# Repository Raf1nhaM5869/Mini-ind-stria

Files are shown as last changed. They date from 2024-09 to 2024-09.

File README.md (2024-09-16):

# Mini Indústria - Robótica
<div align="center">
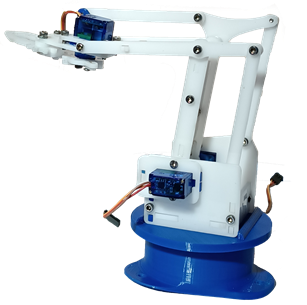
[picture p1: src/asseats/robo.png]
  
</div>

## Realizador
- Rafael Melo (up202405969@fe.up.pt)

## Introdução ao projeto

No ano letivo 2023/2024, no seguimento da apresentação de atividades de Física no Dia da Ciência (24 de novembro), decidi continuar a divulgação de novos trabalhos. Assim, resolvi fazer um projeto que unia diversas áreas científicas, desde a mecânica, eletrónica e informática.
O projeto consiste na simulação do funcionamento de uma secção da indústria, utilizando um braço mecânico e uma passadeira rolante, com os respetivos motores e circuitos, tendo também em conta a sustentabilidade do projeto, que reutilizou materiais, dando-lhes novo uso.
O principal objetivo foi simular uma linha de montagem, que através da união das áreas anteriormente referias, foi possível criar uma passadeira rolante e um pequeno robô, capazes de transportar objetos, através de um comando de PlayStation 3.

## Objetivo do projeto
Na elaboração do projeto, tive como objetivo criar um braço robótico capaz de movimentar um objeto através de motores servos e uma passadeira que transporta um objeto de uma forma estável e rápida.  
Sendo assim, com a criação da passadeira rolante e do braço robótico o funcionamento deveria ser o seguinte: o produto fabricado chegava ao início da passadeira rolante, e este ia percorrer até alcançar o final da mesma. Logo a seguir, o produto para e o robô está pronto a pegá-lo e deslocá-lo para o local desejado. 
Quando o robô pega no produto, este é controlado através de um comando de PlayStation 3, em que os analógicos são usados para obter maior precisão, no decorrer da tarefa. 

## Materiais utilizados
### Braço Robótico 
- `4 motores servo`
  - Os motores servos foram utilizados para articular o braço robótico.  
- `Estrutura do braço em acrílico`

- `Comando de PlayStation 3` 
   - Através do comando de PlayStation , o utilizador consegue controlar o robô, movendo os analógicos, enviando os dados através de Bluetooth para o ESP32.

- `ESP32`
   - O ESP32 permite a comunicação entre o comando PlayStation 3 e os motores servos, permitindo a coordenação entre ambos. 
- `Fio de ligação`

### Passadeira Rolante
- `Borracha`
- `Dois Cilindros de Plástico` 
- `2 Motores de Passo` 
  - Os motores de passos permitem movimentação da passadeira rolante. 
- `Arduíno Uno`
  - O Arduíno Uno permite controlar a velocidade dos motores de passo enviado dados para o módulo L298N e obtém informação através do sonar.
- `Fios de Ligação` 
- `Sonar`

### Equipamento extra
- `Impressora 3D`
  - A impressora 3D permitiu imprimir todas as peças. Assim, obtendo um melhor desempenho no projeto. A marca da impressora é TWO TREES
- `Equipamento de Solda`
- `Multímetro`
- `Transformadores` 
- `Paquímetro`
- `Topia`
### Software 
- `Arduíno IDE`
  - O Arduíno IDE foi o utilizado para programar todos os componentes, como por exemplo, o ESP32, Arduíno Uno, sonar, motores, etc. A linguagem utilizada foi o C++.

- `Fusion 360` 
  - O fusion 360 é um programa de design 3D capaz de satisfazer as necessidades do projeto, uma vez que é possível fazer peças em 3D de uma forma rápida e precisa. Para além disso, no final do projeto, obtenho o ficheiro em STL, possibilitando a sua impressão. 
- `Ultimaker Cura`
  - O Ultimaker Cura é um programa que ajuda a conectar a impressora 3D e definir as características de impressão de cada peça. Através deste software, consegue-se mudar a temperatura de bico de impressão, percentagem de preenchimento, altura do bico ao prato de impressão, velocidade, etc.
- `Fritzing`
  - O Fritzing foi usado para fazer o rascunho dos circuitos elétricos.

<div style="white-space: nowrap;">
  <a href="https://www.arduino.cc/en/software">
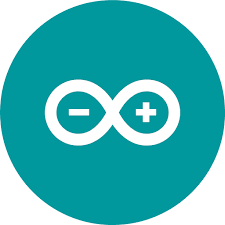
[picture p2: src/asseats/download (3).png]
    
  </a>

  <a href="https://www.autodesk.com/">
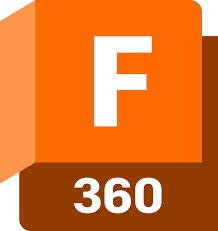
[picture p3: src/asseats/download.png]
    
  </a>

  <a href="https://ultimaker.com/">
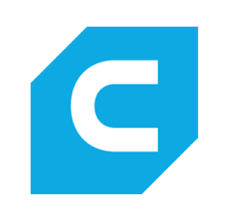
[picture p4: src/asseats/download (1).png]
    
  </a>

  <a href="https://fritzing.org/">
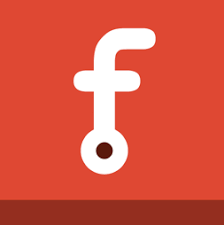
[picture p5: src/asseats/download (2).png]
    
  </a>
</div>

## Implementação
No início do projeto, houve a compra de um kit de um braço robótico em acrílico. Contudo, através da montagem do mesmo, foi detetado diversas anomalias que iam afetar diretamente o devido funcionamento. Sendo assim, efetuei uma análise pormenorizada para solucionar os problemas apresentados no decorrer da montagem. Estes problemas incidiam na parte estrutural, uma vez que toda a estrutura do robô estava afixada no eixo de um motor servo e apresentava algumas peças partidas.
Sendo assim, para criar as estruturas necessárias, utilizou-se a impressora 3D, capaz de fabricar peças personalizadas (tridimensionais e feitas de plástico bastante resistente). 
Assim, para melhorar o desempenho do robô, tive de recorrer à ferramenta anteriormente referia, sendo capaz de resolvê-los. Assim projetaram-se peças com recurso ao FUSION 360.

Nota: Para obter as medidas das peças desejadas necessitei de um paquímetro.
## Peças fabricadas para o braço robótico
### Esta peça é um suporte do braço robótico
Cada imagem está associada a um ficheiro stl da peça.
<p align="center">
  <a href="https://github.com/Raf1nhaM5869/Mini-industria/blob/main/src/objetos%203d/suporte_base.stl">
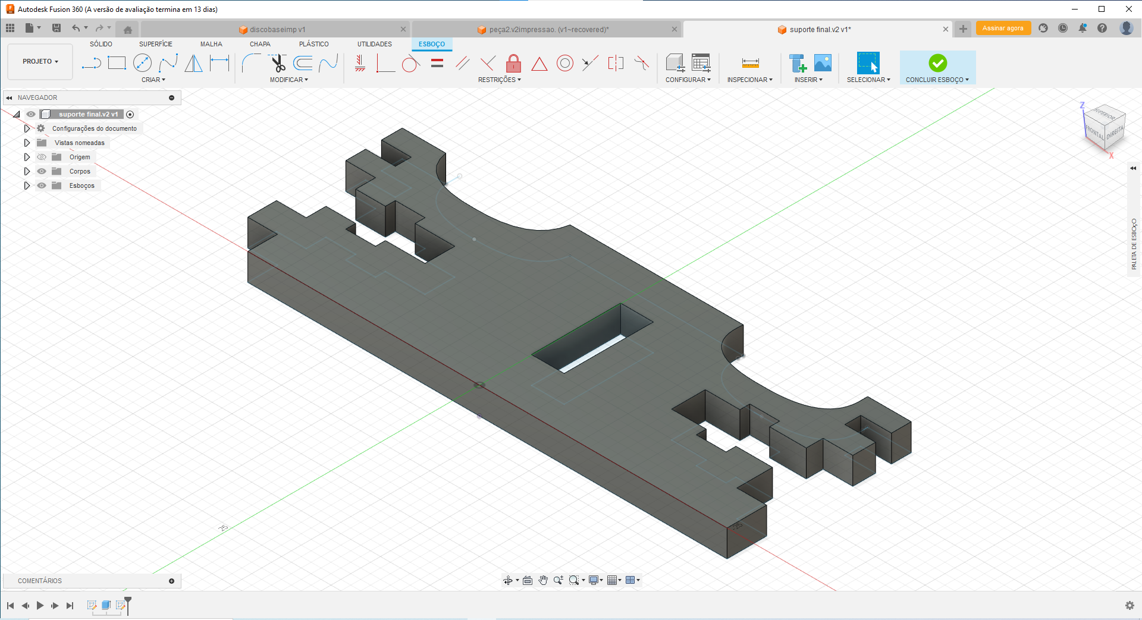
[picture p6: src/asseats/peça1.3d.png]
    
  </a>
  <a href="https://github.com/Raf1nhaM5869/Mini-industria/blob/main/src/asseats/IMG_20231211_163835.jpg">
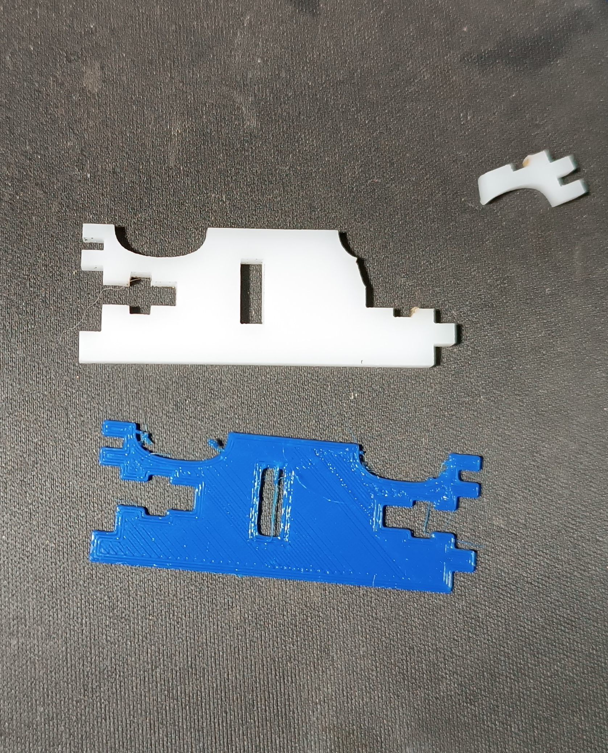
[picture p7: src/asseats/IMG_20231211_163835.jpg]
    
  </a>
</p>

### Suporte da garra à restante estrutura
<p align="center">
  <a href="https://github.com/Raf1nhaM5869/Mini-industria/blob/main/src/objetos%203d/suport_cabe%C3%A7a2.stl">
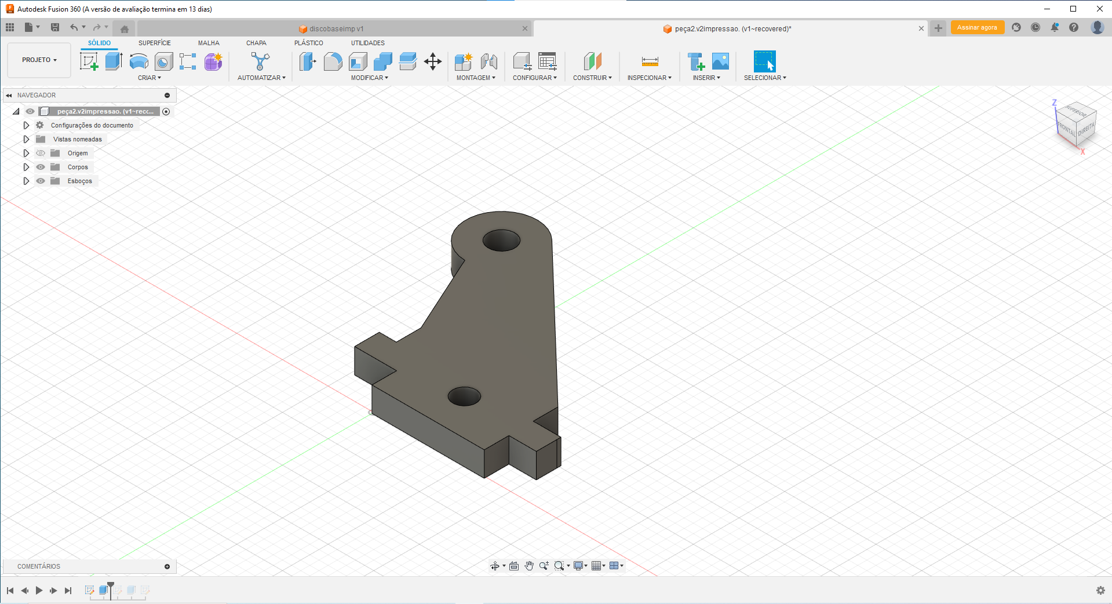
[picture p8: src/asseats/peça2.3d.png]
    
  </a>
  <a href="https://github.com/Raf1nhaM5869/Mini-industria/blob/main/src/objetos%203d/suport_cabe%C3%A7a.stl">
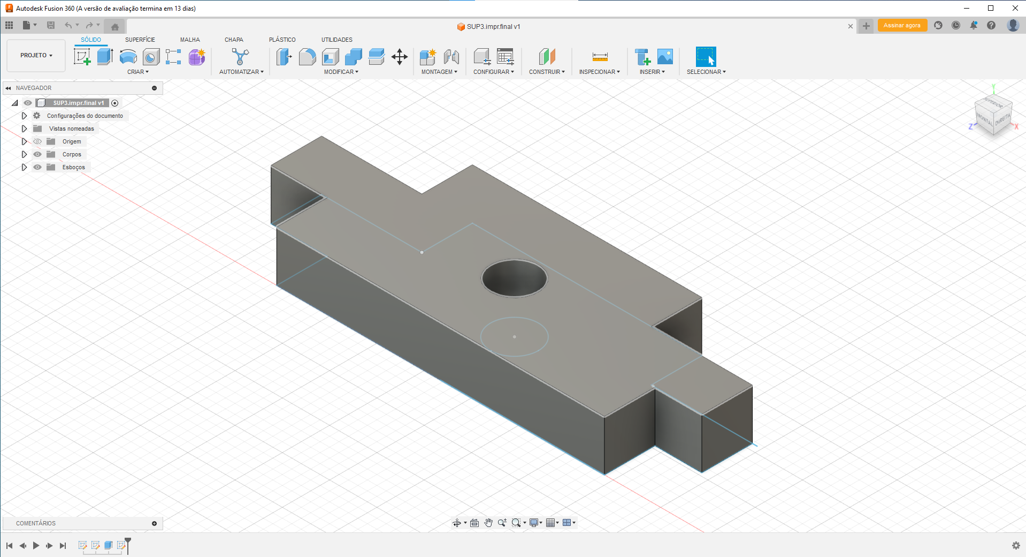
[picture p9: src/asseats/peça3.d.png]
    
  </a>
</p>

<p align="center">
  <a href="https://github.com/Raf1nhaM5869/Mini-industria/blob/main/src/asseats/IMG_20240914_143653.jpg">
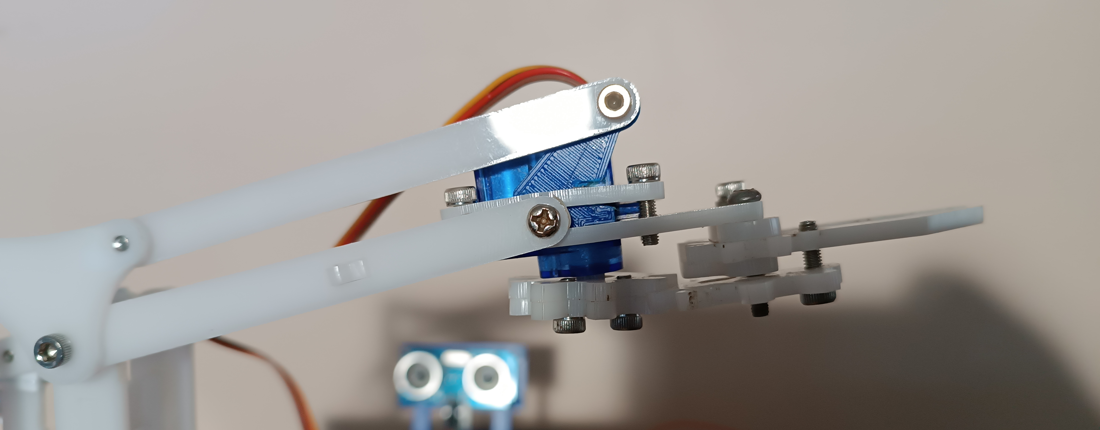
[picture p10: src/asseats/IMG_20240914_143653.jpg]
    
  </a>
  <a href="https://github.com/Raf1nhaM5869/Mini-industria/blob/main/src/asseats/IMG_20240914_143512.jpg">
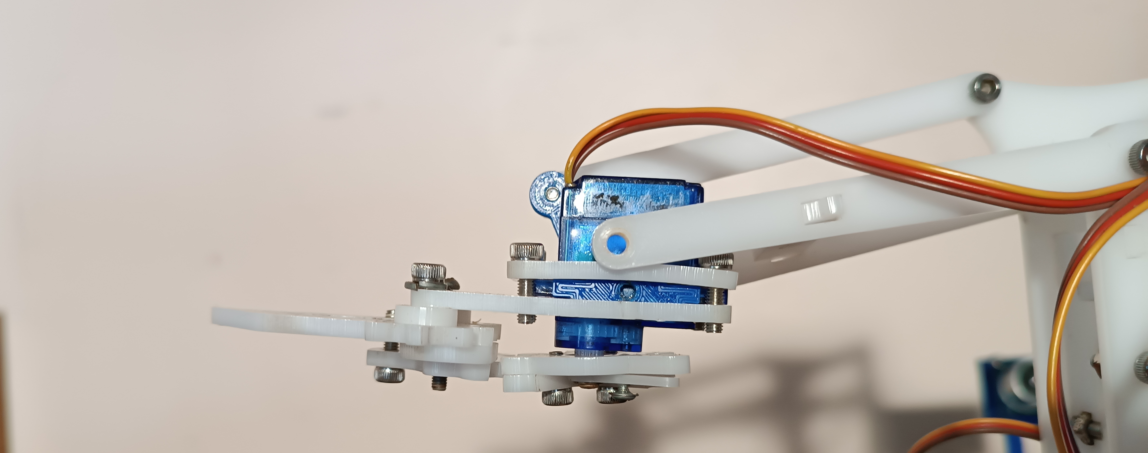
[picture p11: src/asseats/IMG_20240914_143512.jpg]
    
  </a>
</p>

### Disco da Base
<p align="center">
  <a href="https://github.com/Raf1nhaM5869/Mini-industria/blob/main/src/objetos%203d/suport_disco_robo.stl">
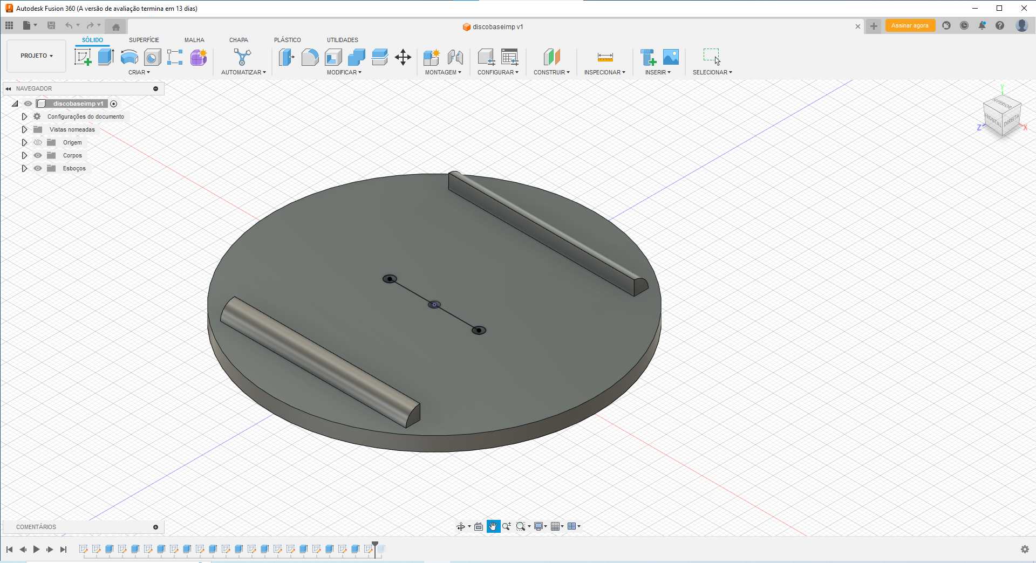
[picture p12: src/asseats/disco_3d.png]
    
  </a>
  <a href="https://github.com/Raf1nhaM5869/Mini-industria/blob/main/src/asseats/IMG_20231218_215923.jpg">
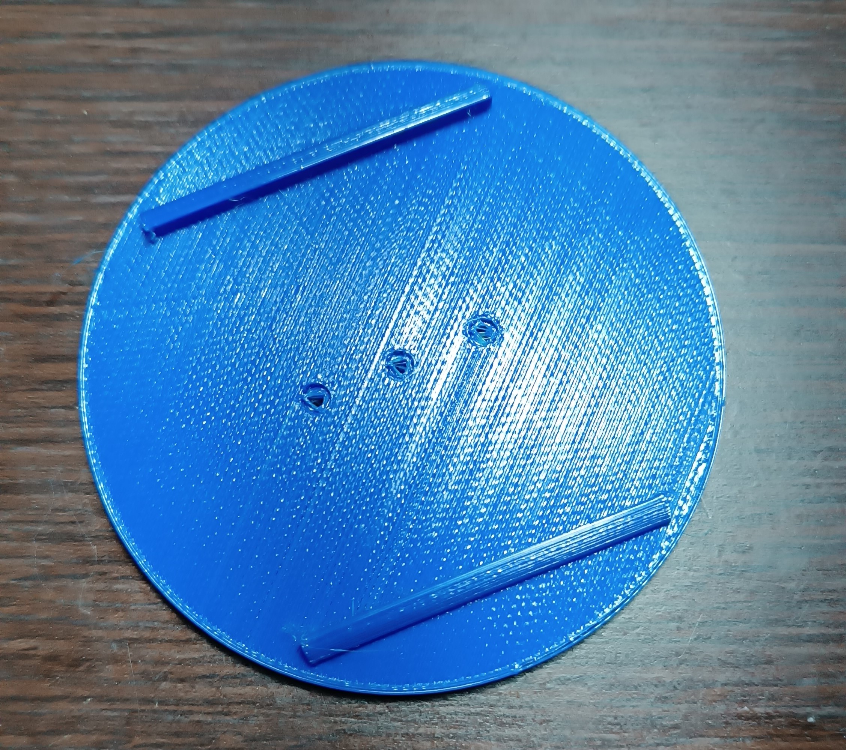
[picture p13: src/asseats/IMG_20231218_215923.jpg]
    
  </a>
</p>

### Base do robô

<p align="center">
  <a href="https://github.com/Raf1nhaM5869/Mini-industria/blob/main/src/objetos%203d/base.stl">
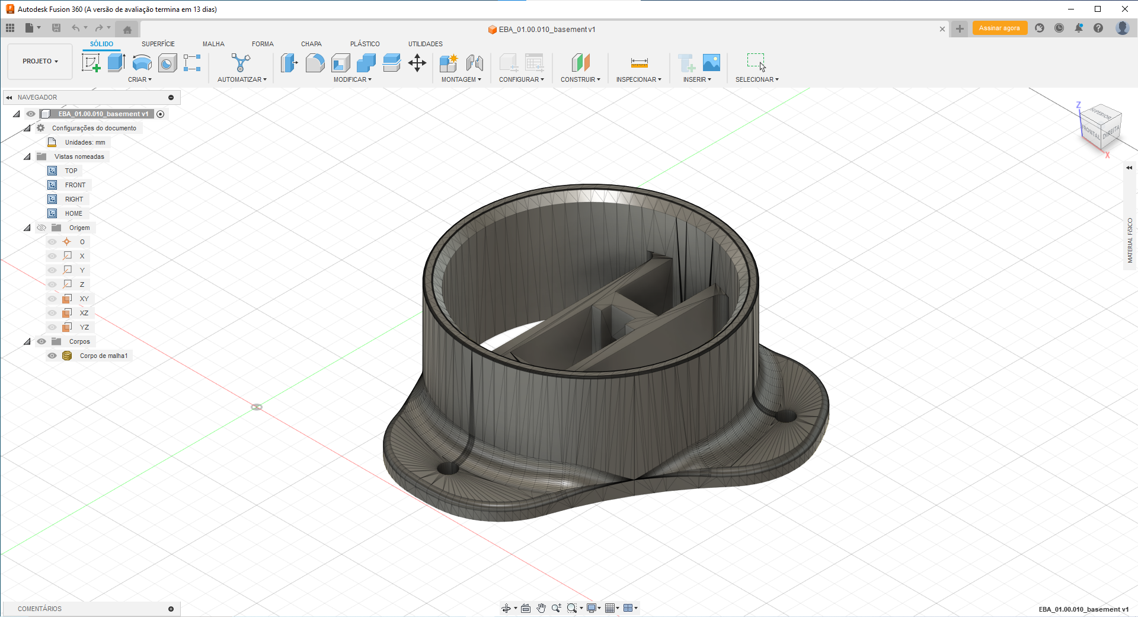
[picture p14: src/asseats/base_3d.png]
Base 3D
    
  </a>
  <a href="https://github.com/Raf1nhaM5869/Mini-industria/blob/main/src/asseats/IMG_20231217_211504.jpg">
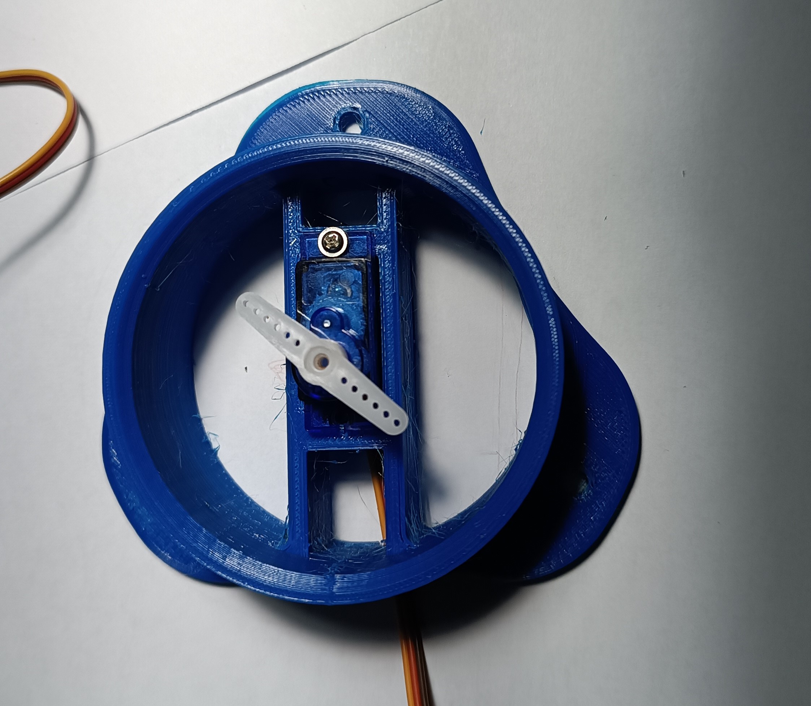
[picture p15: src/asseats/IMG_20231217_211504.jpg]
    
  </a>
</p>

Logo após a criação das peças no fusion 360, estas foram impressas na impressora 3D. Depois de finalizar a impressão 3D, houve a montagem de todas as peças. Antes / depois, respetivamente.

<p align="center">
  <a href="https://github.com/Raf1nhaM5869/Mini-industria/blob/main/src/asseats/IMG_20231128_140823.jpg">
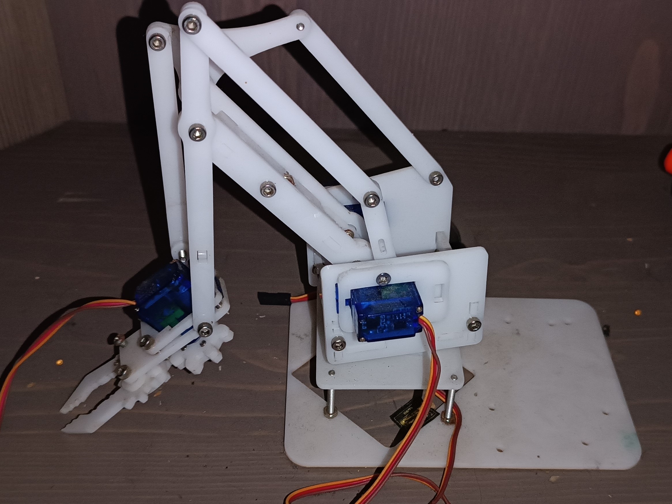
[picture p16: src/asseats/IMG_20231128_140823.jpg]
    
  </a>
  <a href="https://github.com/Raf1nhaM5869/Mini-industria/blob/main/src/asseats/IMG_20240115_205545.jpg">
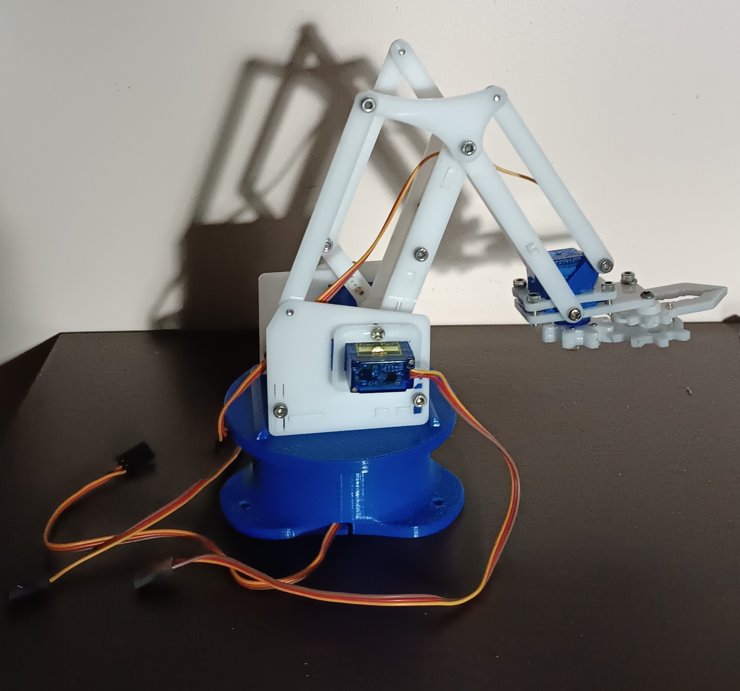
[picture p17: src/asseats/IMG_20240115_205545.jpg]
    
  </a>
</p>

### Instalação do circuito elétrico do robô
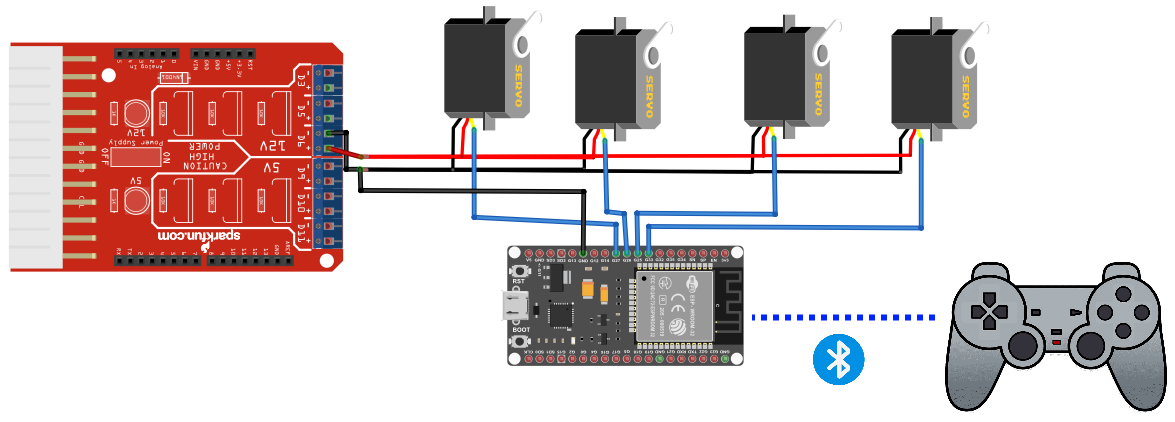
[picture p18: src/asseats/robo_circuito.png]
 

## Peças fabricadas para a passadeira rolante
Na passadeira rolante houve também a necessidade de recorrer ao uso da impressão 3D, para obter estabilidade e mobilidade do tapete. Sendo assim, fiz quatro peças que são as seguintes:

### Espaçador
<p align="center">
  <a href="https://github.com/Raf1nhaM5869/Mini-industria/blob/main/src/objetos%203d/roda.stl">
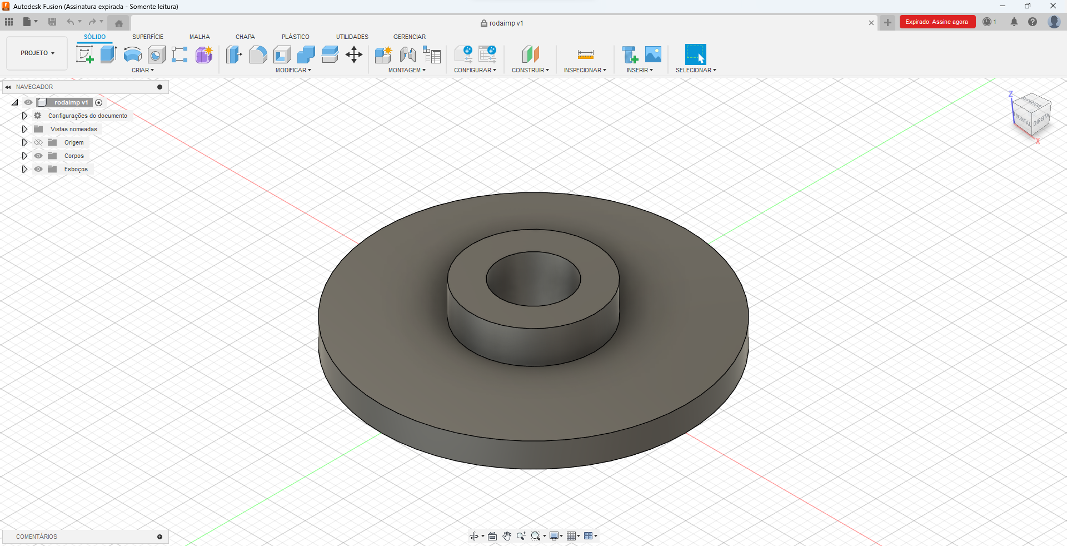
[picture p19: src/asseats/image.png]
    
  </a>
  <a href="https://github.com/Raf1nhaM5869/Mini-industria/blob/main/src/asseats/IMG_20240428_230101.jpg">
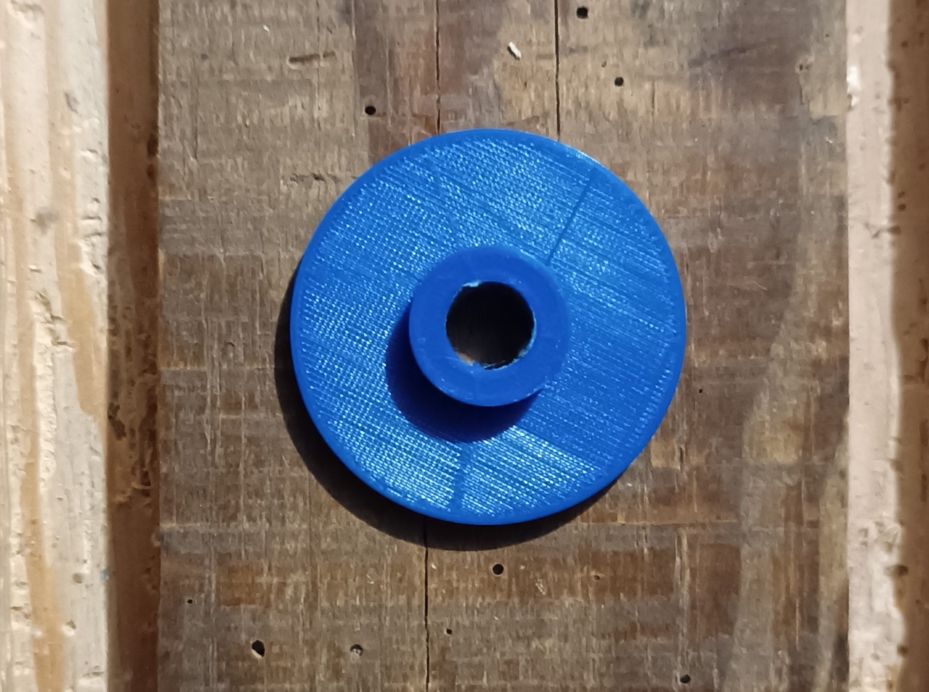
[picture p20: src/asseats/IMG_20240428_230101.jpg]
    
  </a>
</p>

Esta peça foi impressa duas vezes para bloquear a movimentação do rolo de plástico (na horizontal) para não alterar a trajetória.
### Disco Protetor
<p align="center">
  <a href="https://github.com/Raf1nhaM5869/Mini-industria/blob/main/src/objetos%203d/disco_protect.stl">
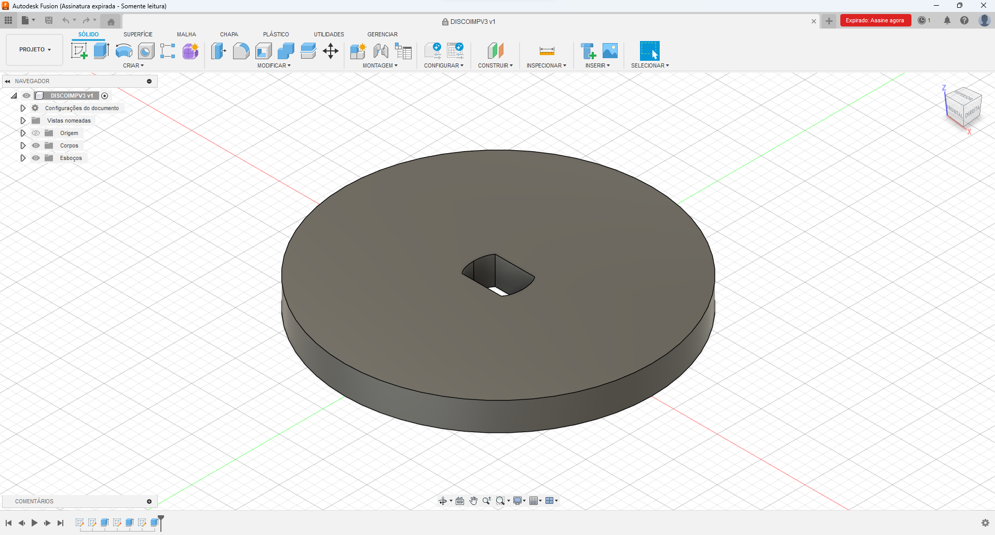
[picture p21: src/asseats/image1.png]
    
  </a>
  <a href="https://github.com/Raf1nhaM5869/Mini-industria/blob/main/src/asseats/IMG_20240914_143739.jpg">
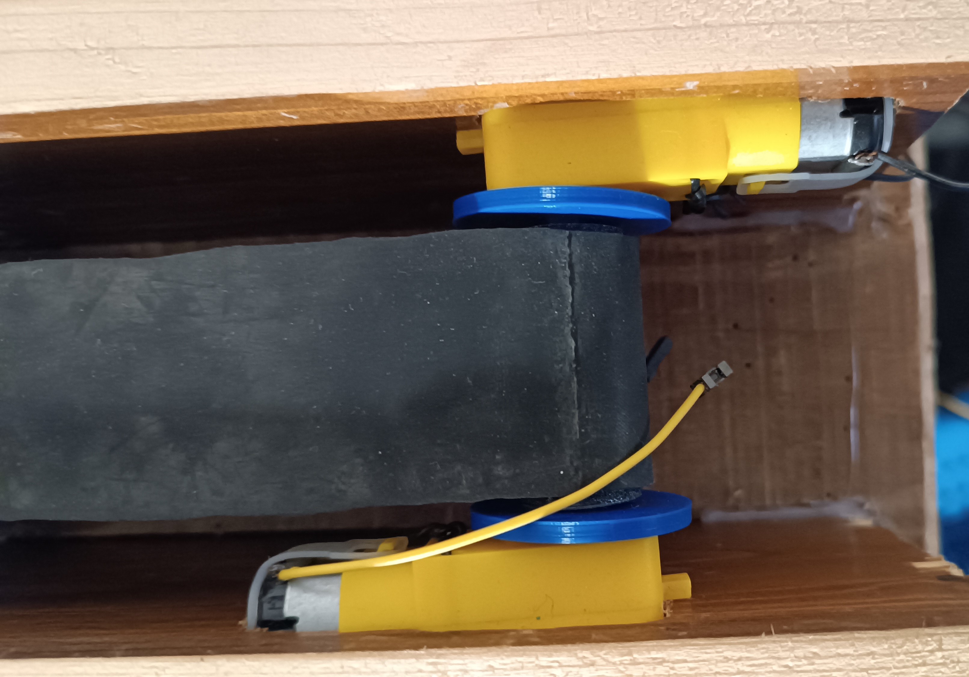
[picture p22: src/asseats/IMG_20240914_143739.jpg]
    
  </a>
</p>

Esta peça foi impressa duas vezes. O objetivo desta peça é igual ao da figura 1, mas também tem outro objetivo que é protege os motores, caso o tapete rolante altere a trajetória.
### Rolo Giratório
<p align="center">
  <a href="https://github.com/Raf1nhaM5869/Mini-industria/blob/main/src/objetos%203d/rolo_giratorio.stl">
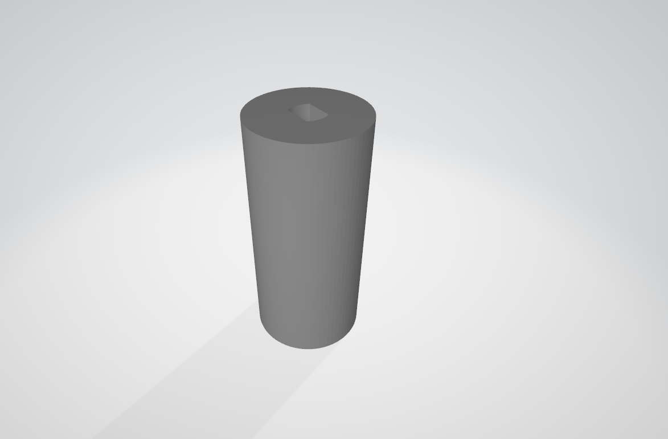
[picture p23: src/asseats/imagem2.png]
    
</p>

Esta peça estabelece a ligação entre os motores de passo e a passadeira, transmitindo-lhe movimento. Esta tem uma lixa tem toda a sua volta, para ter maior atrito entre a peça e a borracha, obtendo maior eficiência.

### Suporte do sonar
<p align="center">
  <a href="https://github.com/Raf1nhaM5869/Mini-industria/blob/main/src/objetos%203d/suporte_sonar.stl">
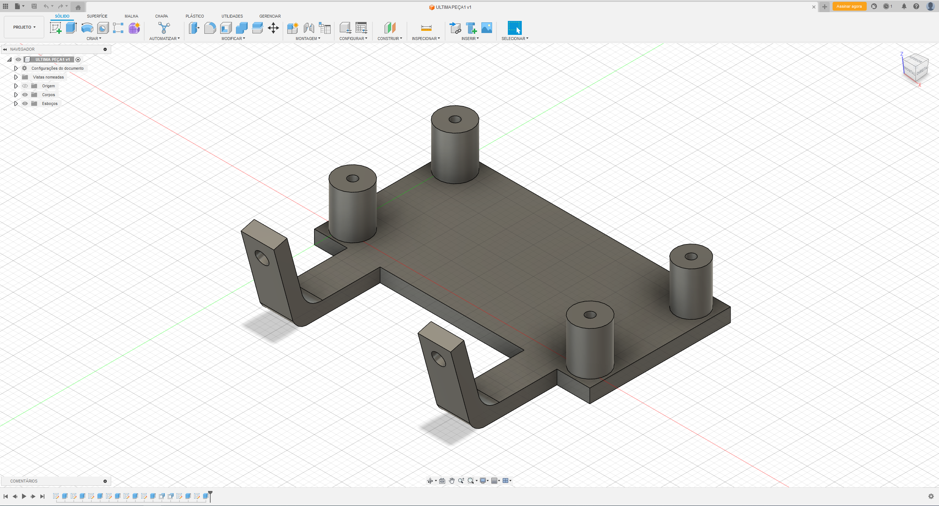
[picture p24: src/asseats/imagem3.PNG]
    
  </a>
  <a href="https://github.com/Raf1nhaM5869/Mini-industria/blob/main/src/asseats/IMG_20240914_143821.jpg">
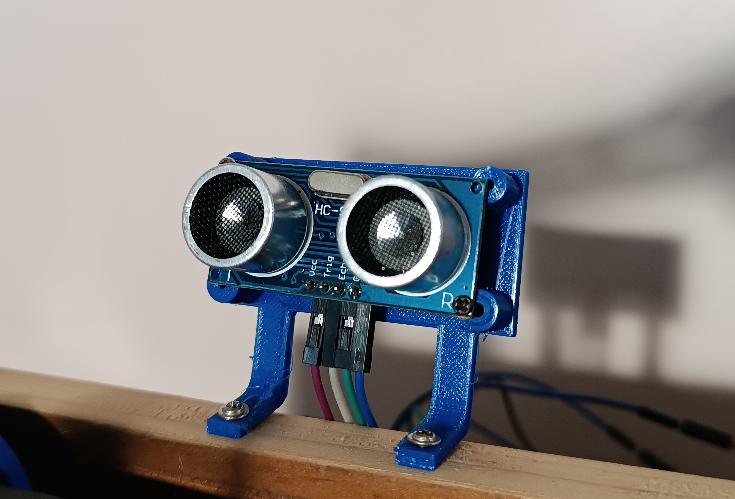
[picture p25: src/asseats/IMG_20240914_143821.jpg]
    
  </a>
</p>

Esta peça é um suporte do sensor ultrassónico para possibilitar a deteção o objeto.

Após a impressão das peças, houve a montagem. 

<p align="center">
  <a href="https://github.com/Raf1nhaM5869/Mini-industria/blob/main/src/asseats/IMG_20240916_205601.jpg">
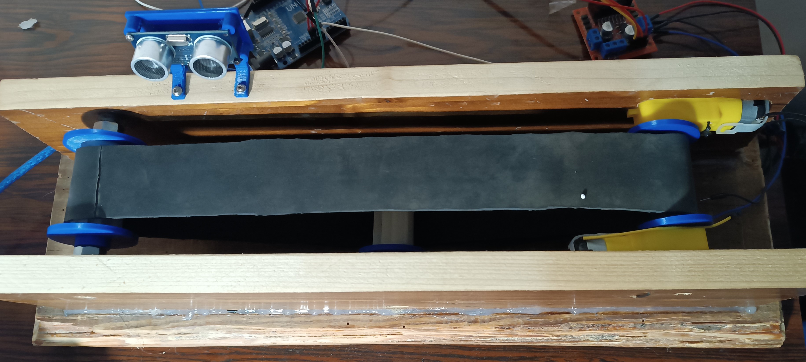
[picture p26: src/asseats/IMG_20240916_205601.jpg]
    
</p>

### Instalação do circuitos elétricos da passadeira rolante

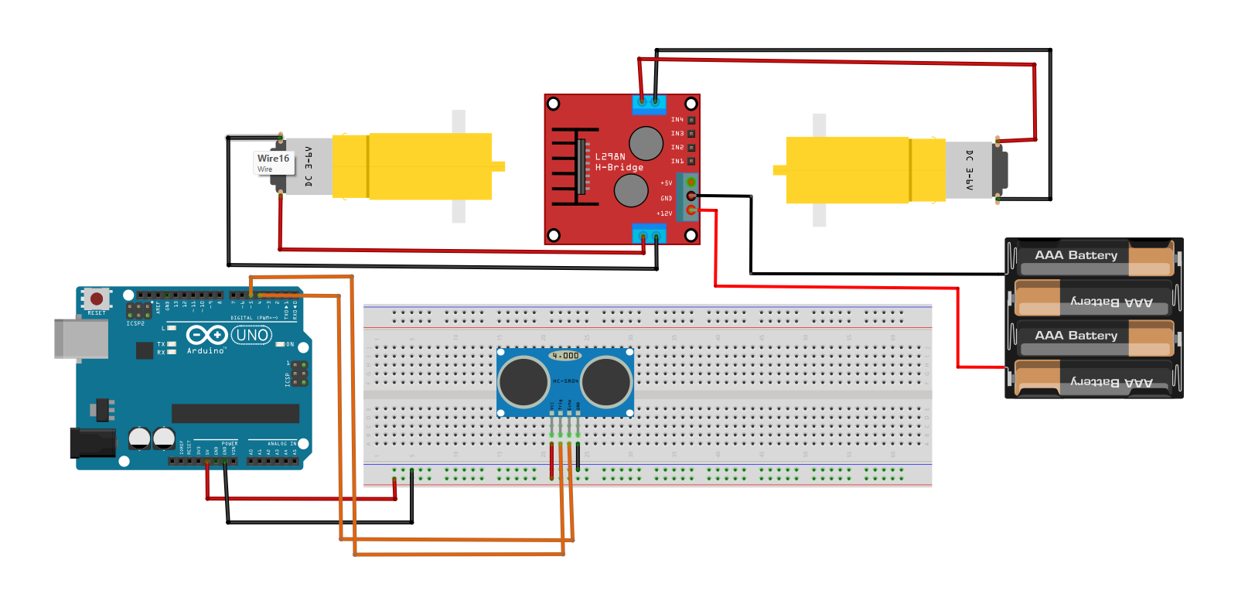
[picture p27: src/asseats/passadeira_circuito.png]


## Conclusão

Em suma, o projeto foi bem concebido, uma vez que o objetivo inicial de fazer uma secção de indústria foi cumprido. Para além disso, o projeto pode apresentar diferente configurações tornando-o mais autónomo ou mais interativo. A configuração apresentada do robô é mais interativa devido ao objetivo final de apresentar a qualquer faixa etária. Sendo assim, o único pormenor que não foi realizado foi outra configuração mais autónoma em que o braço robótico e a passadeira comunicassem entre si.

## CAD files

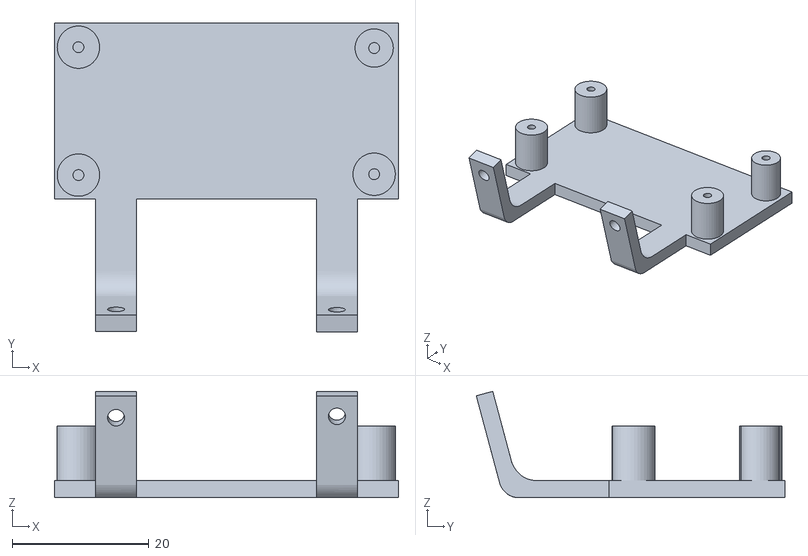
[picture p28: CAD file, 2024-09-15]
src/objetos 3d/suporte_sonar.stl
50.3 x 45.1 x 15.5

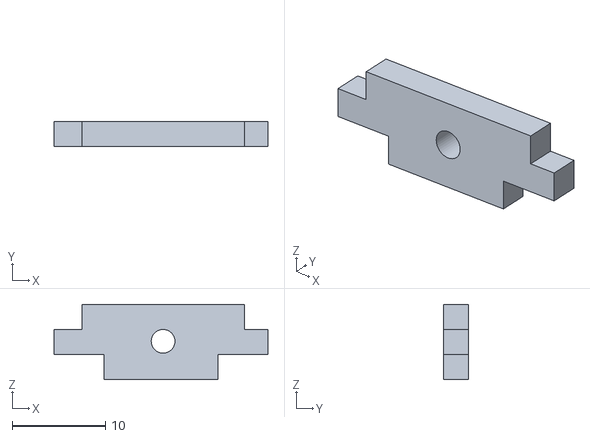
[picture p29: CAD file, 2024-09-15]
src/objetos 3d/suport_cabeça.stl
23.0 x 2.70 x 8.10

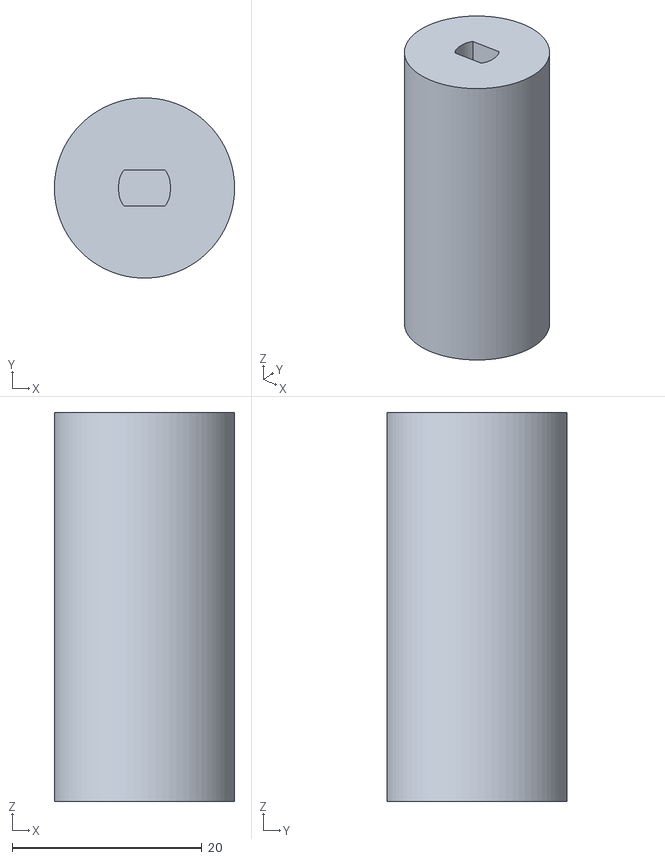
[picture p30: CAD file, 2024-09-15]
src/objetos 3d/rolo_giratorio.stl
19.0 x 19.0 x 41.0

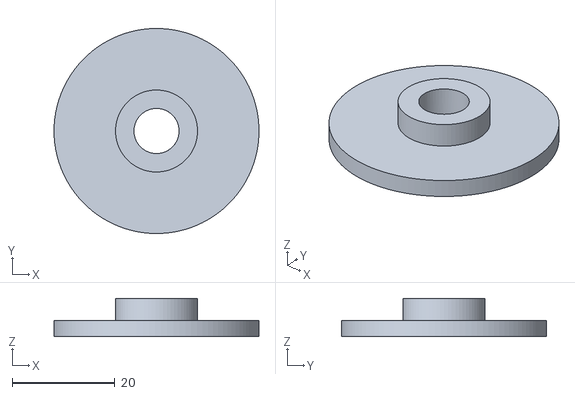
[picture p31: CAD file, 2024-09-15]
src/objetos 3d/roda.stl
40.0 x 40.0 x 7.50

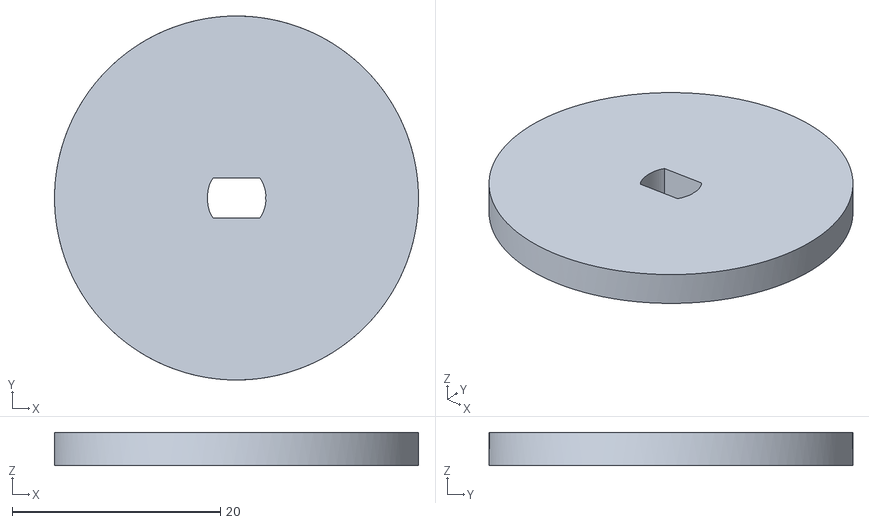
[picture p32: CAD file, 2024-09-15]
src/objetos 3d/disco_protect.stl
35.0 x 35.0 x 3.20

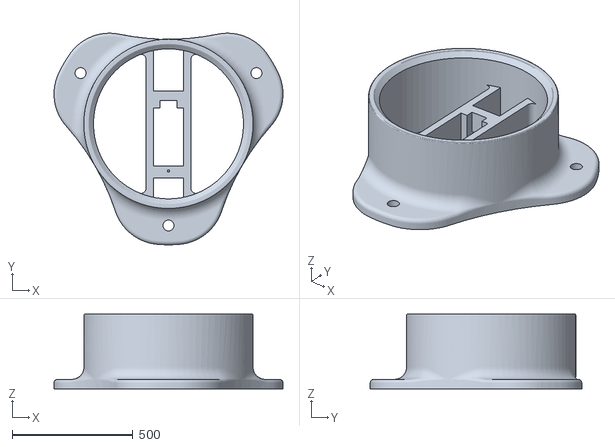
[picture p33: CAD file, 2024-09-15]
src/objetos 3d/base.stl
946.7 x 874.6 x 310.0

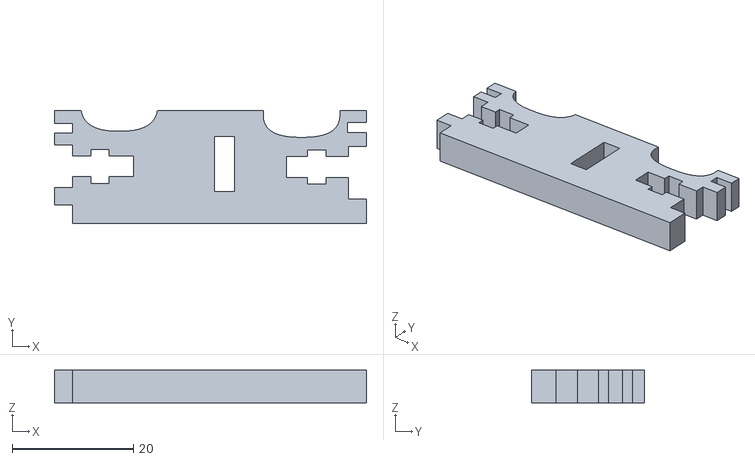
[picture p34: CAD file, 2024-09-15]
src/objetos 3d/suporte_base.stl
51.4 x 18.6 x 5.40

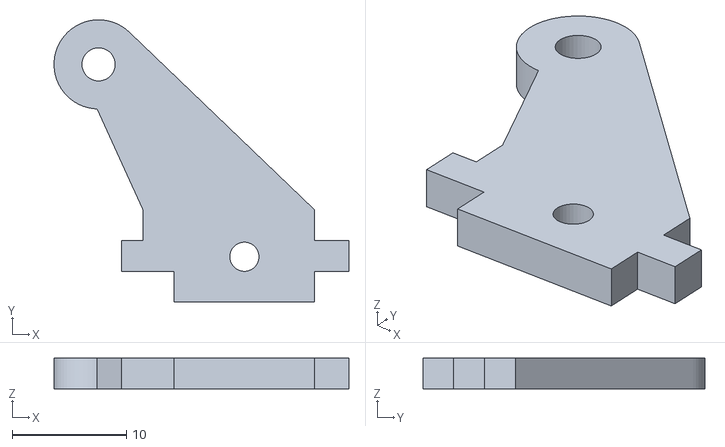
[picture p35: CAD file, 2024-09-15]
src/objetos 3d/suport_cabeça2.stl
25.8 x 24.7 x 2.70

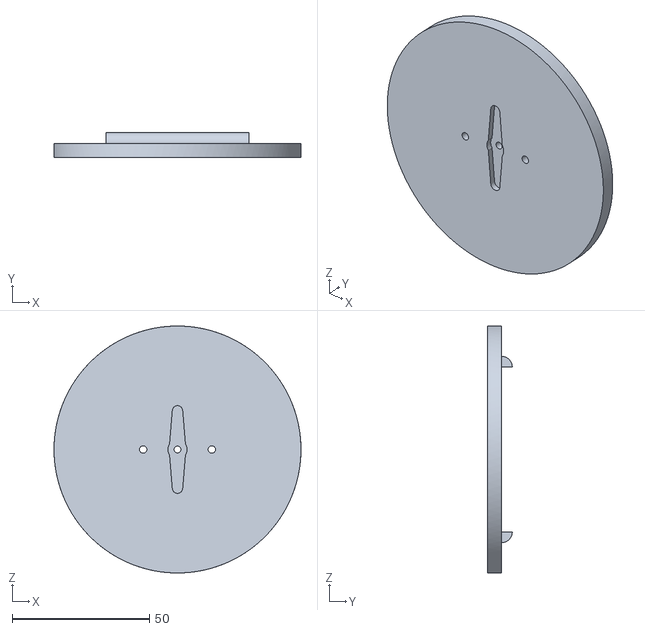
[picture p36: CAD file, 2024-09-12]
src/objetos 3d/suport_disco_robo.stl
90.0 x 9.00 x 90.0

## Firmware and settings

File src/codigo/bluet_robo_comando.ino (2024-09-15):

#include <Ps3Controller.h> 
#include <ESP32Servo.h>

Servo servoL;
Servo servoR;
Servo servoB;
Servo servoC;

int rX;
int rY;
int lX;
int lY;

int posR = 90;
int posL = 90;
int posB = 90;
int posC = 90;

void notify()
{
   lX =(Ps3.data.analog.stick.lx);
   lY =(Ps3.data.analog.stick.ly);
   rX =(Ps3.data.analog.stick.rx);
   rY =(Ps3.data.analog.stick.ry);
   Serial.print(lX);
    Serial.println();
   Serial.print(lY);
    Serial.println();
   Serial.print(rX);
    Serial.println();
   Serial.print(rY);
   if (lY < -50 && posR<180) {
     posR++;
     servoR.write(posR);
     delay(10);
   }
   if (lY > 50 && posR>0) {
     posR--;
     servoR.write(posR);
     delay(10);
   }

   if (rY < -50 && posL<180) {
     posL++;
     servoL.write(posL);
     delay(10);
   }
   if (rY > 50 && posL>0) {
     posL--;
     servoL.write(posL);
     delay(10);
   }
   if (rX < -50 && posB<180) {
     posB++;
     servoB.write(posB);
     delay(10);
   }
   if (rX > 50 && posB>0) {
     posB--;
     servoB.write(posB);
     delay(10);
   }

   if( abs(Ps3.event.analog_changed.button.r2)>50 && posC > 0 ){
     Serial.print("Pressing the right trigger button: ");
     Serial.println(Ps3.data.analog.button.r2, DEC);
     posC--;
     if (posC<1 ) {
        posC=1;
     }
     servoC.write(posC);
     delay(10); 
   }

   if( abs(Ps3.event.analog_changed.button.l2)>50 && posC < 180 ){
     Serial.print("Pressing the left trigger button: ");
     Serial.println(Ps3.data.analog.button.l2, DEC);
     posC++;
     if (posC>179) {
        posB=179;
     }
     servoC.write(posC);
     delay(10);
   }
   
   if( abs(Ps3.event.analog_changed.button.right)>50  && posB>0 ){
       Serial.print("Pressing the right button: ");
       Serial.println(Ps3.data.analog.button.right, DEC);
       posB--;
       if (posB<1 ) {
        posB=1;
       }
       servoB.write(posB);       
       delay(10);
   }

   if( abs(Ps3.event.analog_changed.button.left)>50 && posB<180 ){
       Serial.print("Pressing the left button: ");
       Serial.println(Ps3.data.analog.button.left, DEC);
       posB++;
       if (posB>179) {
        posB=179;
       }
       servoB.write(posB);
       delay(10);   
   }      
 
}

void onConnect(){
   Serial.println("Connected.");
}

void setup() {
    Serial.begin(115200);
    Ps3.attach(notify);
    Ps3.attachOnConnect(onConnect);
    Ps3.begin("fc:b4:67:92:1b:46");
    servoL.attach(25);
    servoR.attach(26);
    servoB.attach(27);
    servoC.attach(33);    
    servoL.write(posL);
    servoR.write(posR);
    servoB.write(posB);
    servoC.write(posC);
}

void loop() {
    if (!Ps3.isConnected()) {
      return;
    }
    if( Ps3.data.button.l2 && Ps3.data.button.r2 )
        Serial.println("Pressing both the left and right trigger buttons");       
 
    delay(2000);
}

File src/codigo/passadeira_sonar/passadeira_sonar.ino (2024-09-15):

#define m1a 6
#define m1b 9
#define m2a 10
#define m2b 11
#define tmp 3000

int vel=100;


long readUltrasonicDistance(int triggerPin, int echoPin)
{
  pinMode(triggerPin, OUTPUT);  // Clear the trigger
  digitalWrite(triggerPin, LOW);
  delayMicroseconds(2);
  // Sets the trigger pin to HIGH state for 10 microseconds
  digitalWrite(triggerPin, HIGH);
  delayMicroseconds(10);
  digitalWrite(triggerPin, LOW);
  pinMode(echoPin, INPUT);
  // Reads the echo pin, and returns the sound wave travel time in microseconds
  return pulseIn(echoPin, HIGH);
}

void setup()
{
  pinMode(m1a,OUTPUT);
  pinMode(m1b,OUTPUT);
  pinMode(m2a,OUTPUT);
  pinMode(m2b,OUTPUT);
  
  pinMode(0, OUTPUT);
  Serial.begin(9600);

}

void loop()
{
  tone(0, 523, 1000); // play tone 60 (C5 = 523 Hz)
  Serial.println(0.01723 * readUltrasonicDistance(5, 4));
  if (0.01723 * readUltrasonicDistance(5, 4) < 10) {
    vel=0;
    analogWrite(m1a,vel);
    analogWrite(m1b,vel);
    analogWrite(m2a,vel);
    analogWrite(m2b,vel);

  } else {
    vel=100;
    analogWrite(m1a,vel);
    analogWrite(m1b,vel);
    analogWrite(m2a,vel);
    analogWrite(m2b,vel);
  }
  delay(10); // Delay a little bit to improve simulation performance
}
